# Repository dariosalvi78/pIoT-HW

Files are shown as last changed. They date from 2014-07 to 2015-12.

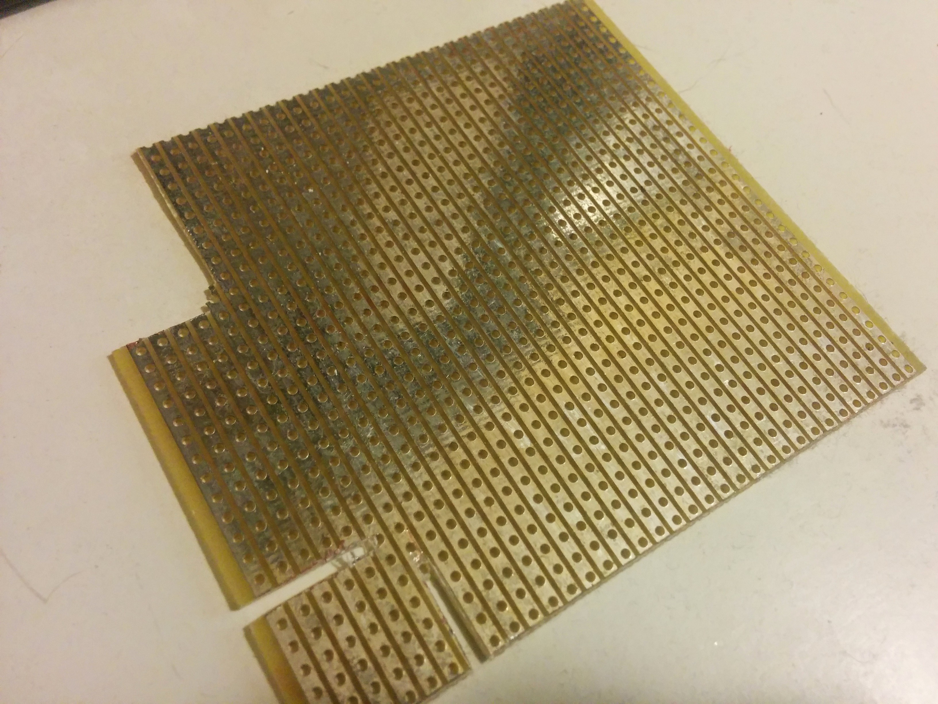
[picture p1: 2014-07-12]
pictures/adapter_pcb2.jpg

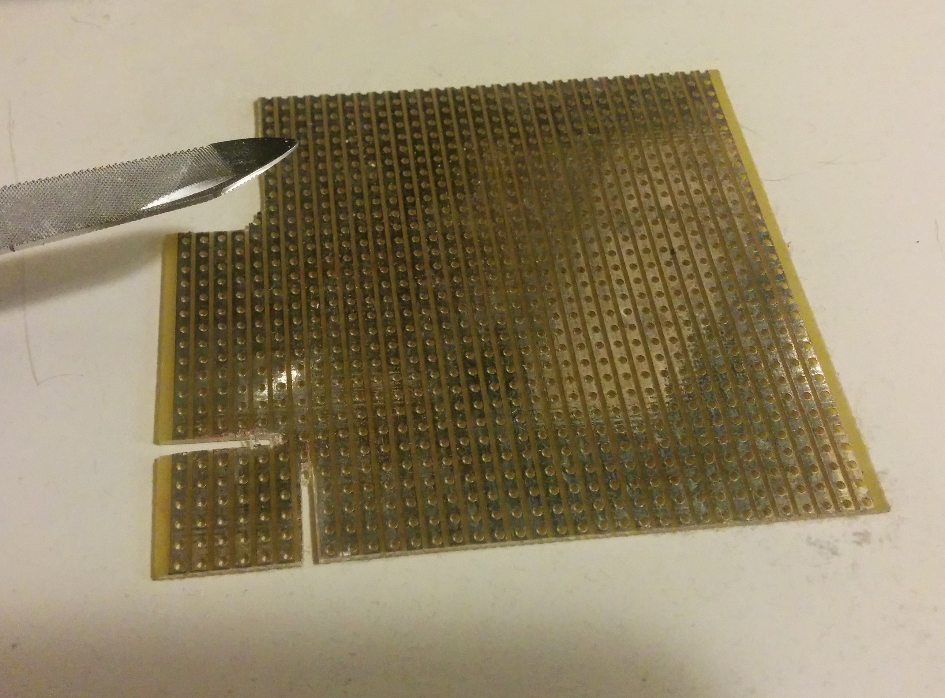
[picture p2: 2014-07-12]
pictures/adapter_pcb.jpg

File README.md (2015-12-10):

 pIoT-HW
===========================================================================================

pIoT is an open source pico/personal framework for the Internet of Things (IoT).
It includes a hardware design for low-cost, low-power, Arduino compatible boards, a C++ library for programming the board and a simple server application that stores data and offers web visualization.

This repo contains the design of the hardware board.

Requirements of the board
-------------------------

1.  it has to be compatible with the Arduino environment
2.  it must include radio communication means
2.  building the basic board should cost less than 5€
3.  it has to be able to last years with standard batteries

Design decisions
----------------

*  Microcontroller: ATMega 328p, the same as Arduino Uno
*  Radio module: nrf24L01+

Details
-------

The hardware design is simply an ATMega328p connected to an nRF24L01.
You need to program the ATMega328 following the tutorial on [Arduino to Breadboard](https://www.arduino.cc/en/Tutorial/ArduinoToBreadboard).

In this repo you can find:

*  a [Fritzing](http://fritzing.org/home/) [schema of the board](https://github.com/dariosalvi78/pIoT-HW/blob/master/pIoT.fzz)
*  the [connections schema](https://github.com/dariosalvi78/pIoT-HW/blob/master/connections.md) of the board
*  the [boards.txt](https://github.com/dariosalvi78/pIoT-HW/blob/master/boards.txt) file to be added in the hardware folder in the sketch folder of your Arduino IDE, lternatively, you can use the Arduino mini pro at 3.3V which is compatible with this one
*  [images](https://github.com/dariosalvi78/pIoT-HW/tree/master/pictures) of some prototypes

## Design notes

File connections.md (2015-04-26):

Pins connections
================

Description of the connections among pins of the MCU, the radio module and the external parts.

Atmega-radio connections
------------------------

    ATMEGA      -> NRF24L01

    PIN 4  PD2  -> PIN 8 NRF24 (IRQ)
    PIN 15 PB1  -> PIN 3 NRF24 (CE)
    PIN 16 PB2  -> PIN 4 NRF24 (CSN)
    PIN 17 PB3  -> PIN 6 NRF24 (MOSI)
    PIN 18 PB4  -> PIN 7 NRF24 (MISO)
    PIN 19 PB5  -> PIN 5 NRF24 (SCK)

Power connections
-----------------

    ATMEGA      -> Power

    PIN 7 VCC   -> 3V
    PIN 8 GND   -> GND
    PIN 20 AVCC -> 3V (!!!)

    NRF24L01    -> Power

    PIN 1 GND   -> GND
    PIN 2 VCC   -> 3V

Optional: for energy savings, the NRF24 module can be powered up/down by the MCU. Using a NPN transistor like the cheap BC547 and a digital pin (eg digital pin 8), the connection would be the following:

    ATMEGA      -> BC547

    PIN 14 PB0  -> Base

    NRF24L01    -> BC547

    PIN 1 GND   -> Collector

    BC547       -> Power

    Emitter     -> GND

Programmer connections
----------------------
In order to be able to program the ATMega from the pC, you need a USB to serial converter. Important: it must allow 3V or you will burn the nrf24 module. There are several on the Market, I have used one based on the FTDI chip which allows 5V and 3.3V, see this [example](http://www.miniinthebox.com/es/programa-ftdi-basico-downloader-usb-a-ttl-ft232-para-arduino_p903425.html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). 

For the connections, you will need some extra components, as the DTR pin from these serial converters are not compatible with the reset pin as it is used in Arduino. An example is available at [this link](http://www.modsbyus.com/use-the-ftdi-basic-breakout-board-to-program-an-atmega328p-pu-with-optiboot/) or [this](http://www.psyelmer9.info/3/post/2012/05/may-17th-2012.html).

    ATMEGA      -> Programmer

    PIN 2 PD0   -> TX
    PIN 3 PD1   -> RX
	
	Other:
	
	GND on Programmer -> common GND on pIoT board
	VCC on Programmer -> common Vcc on pIoT board
	
	PIN 1 PC6   -> 100nF cap
	100nF cap   -> DTR
	PIN 1 PC6   -> 10KO res
	10KO res    -> VCC on Programmer

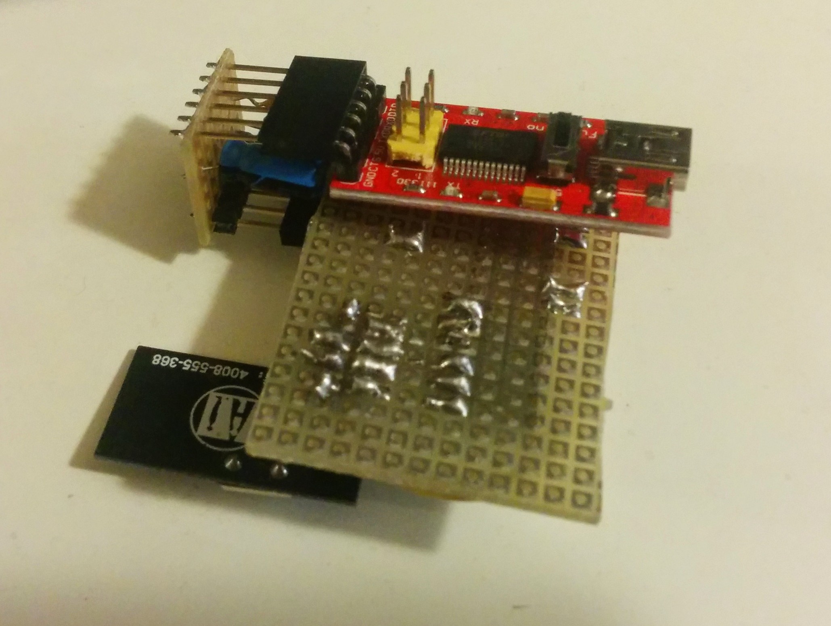
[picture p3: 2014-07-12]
pictures/node_adapter_ftdi.jpg

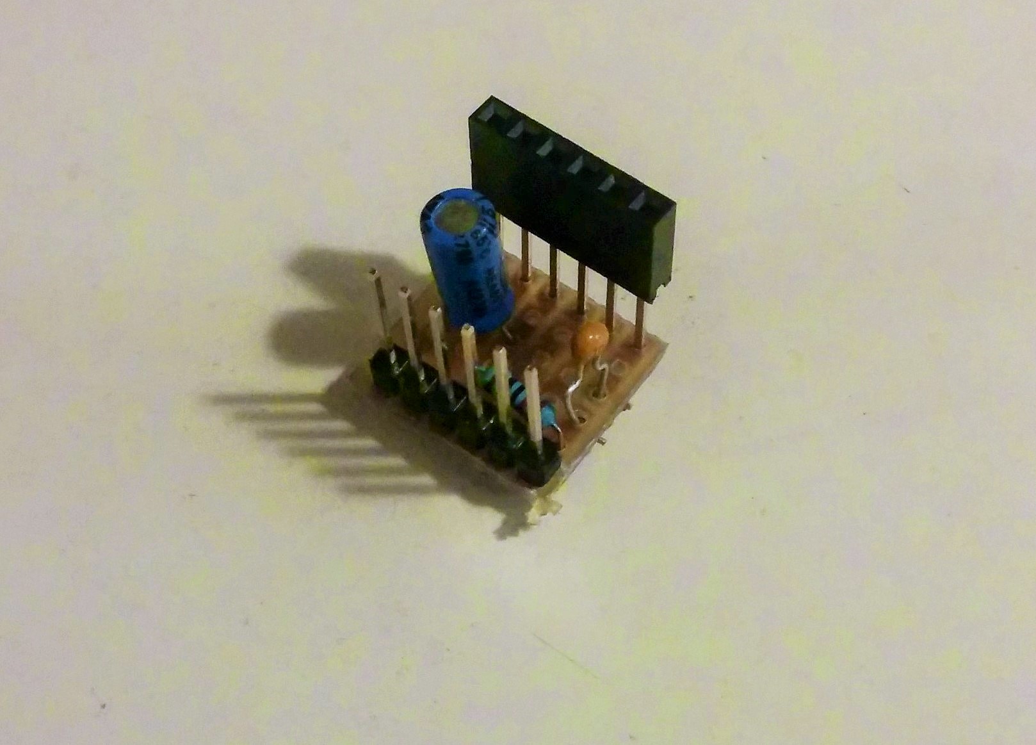
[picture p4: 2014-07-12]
pictures/adapter.jpg

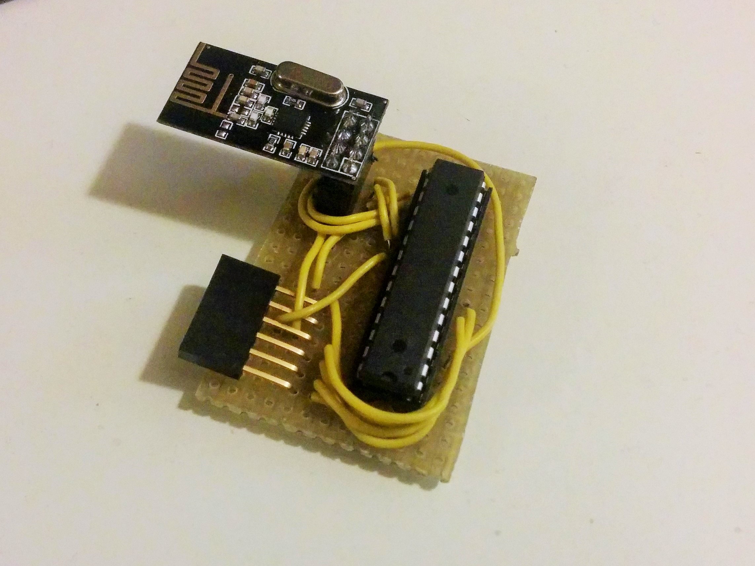
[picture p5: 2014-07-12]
pictures/node.jpg

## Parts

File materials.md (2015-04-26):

Bill of materials
=================

*  **ATMega328p**: 1.3€ on [Aliexpress](http://www.aliexpress.com/item/free-shipping-20pcs-lot-ATMEGA328P-PU-CHIP-ATMEGA328-Microcontroller-MCU-AVR-32K-20MHz-FLASH-DIP-28/1739614617.html)
*  **nRF24L01+ module**: 0.7€ on [Aliexpress](http://www.aliexpress.com/item/Free-shiping-best-prices-10pcs-lot-NRF24L01-NRF24L01-Wireless-Module-2-4G-Wireless-Communication-Module/674686536.html)
*  5x7cm **PCB board**: 0.14€ on [Aliexpress](http://www.aliexpress.com/item/50pcs-Prototype-Paper-PCB-Universal-Experiment-Matrix-Circuit-Board-5x7cm-Free-Shipping/1308577360.html)
*  **electric cable**: 0.1€ (estimated)
*  **2xAA batteries holder**: 0.5€ on [Alixpress](http://www.aliexpress.com/item/Samples-10Pcs-lot-2-AA-Battery-Case-Holder-Box-Base-Socket-With-15cm-Wires-Battery-Holder/1857962901.html)

**Total**: 2.74€

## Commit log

2014-06-22 Adding the first Fritzing approximation
    [pIoT.fzz]
2014-08-20 more explicit boards.txt
2014-10-31 lowered brow-out detection to 1.8V
